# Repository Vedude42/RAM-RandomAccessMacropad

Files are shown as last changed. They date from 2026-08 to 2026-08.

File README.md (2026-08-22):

# RAM-RandomAccessMacropad
A macropad that is used for any random keyboard shortcuts and buttons that I dont have on my keyboard
MacroPad

# Schematics




# PCB





# Case







# FirmWare

right now, the firmware is just a numberpad, but when I assemble My macropad I'm going to set it to random miscellaneous shortcuts.

# Bom

You can find the Bom in the PCB Folder (Along with a zip file that you can import straight into jlcpcp for fabrication) with the footprints of the parts. keycaps are DSA 1us

- Seed XIAO RP2040 Microcontroller
- 16x Mechanical switches
- 1x 0.91 inch oled display
- 4 20mm m4 screws
- 16x dsa keycaps

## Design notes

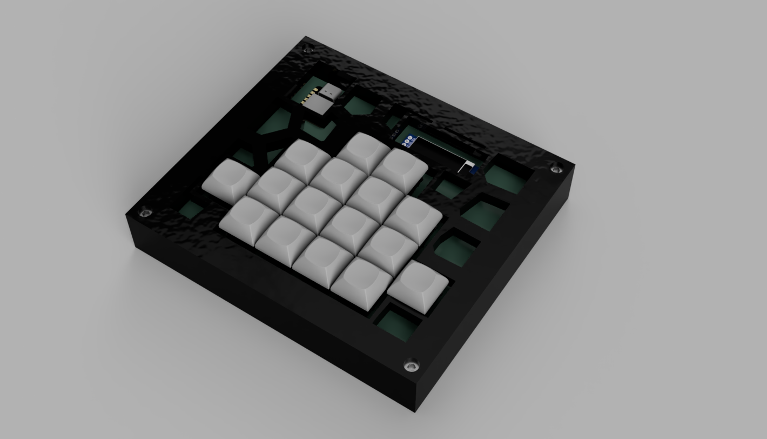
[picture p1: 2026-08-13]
MacroPad.png

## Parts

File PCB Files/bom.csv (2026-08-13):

Designator | Footprint | Quantity | Value | LCSC Part #
D1, D10, D11, D12, D13, D14, D15, D16, D2, D3, D4, D5, D6, D7, D8, D9 | D_DO-35_SOD27_P7.62mm_Horizontal | 16 | D
J1 | SSD1306-0.91-OLED-4pin-128x32 | 1 | Conn_01x04_Pin
SW1, SW10, SW11, SW12, SW13, SW14, SW15, SW16, SW2, SW3, SW4, SW5, SW6, SW7, SW8, SW9 | SW_Cherry_MX_1.00u_PCB | 16 | SW_Push_45deg
U1 | XIAO-Generic-Hybrid-14P-2.54-21X17.8MM | 1 | MOUDLE-SEEEDUINO-XIAO

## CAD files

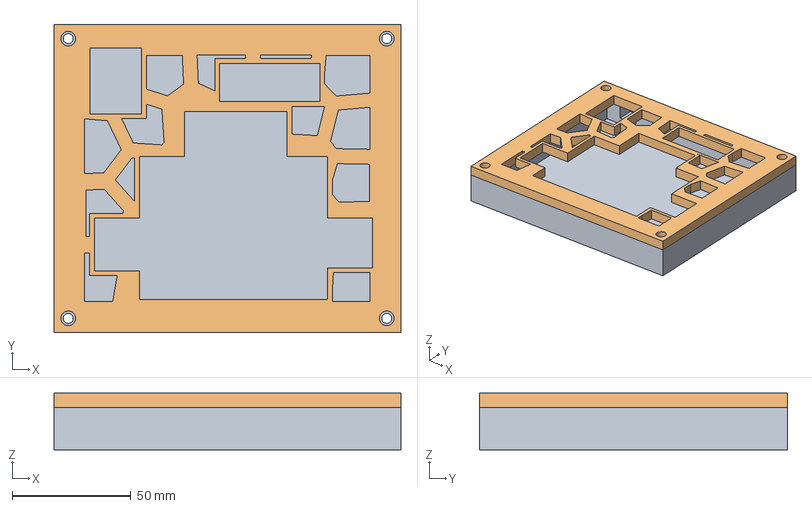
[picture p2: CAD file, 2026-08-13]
production/3D Elements/MacroPad.step
146.4 x 130.0 x 24.0 mm

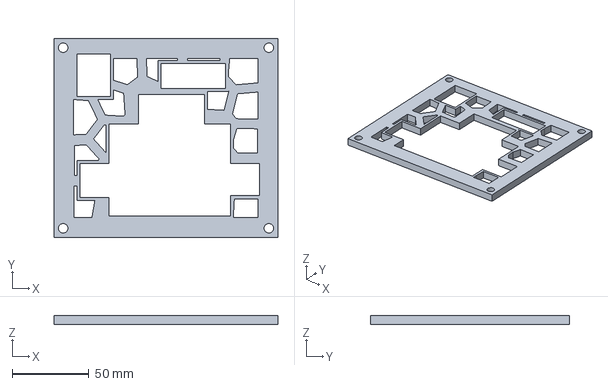
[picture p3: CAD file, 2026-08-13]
production/3D Elements/MacroPad Top Plate.step
146.4 x 130.0 x 6.00 mm

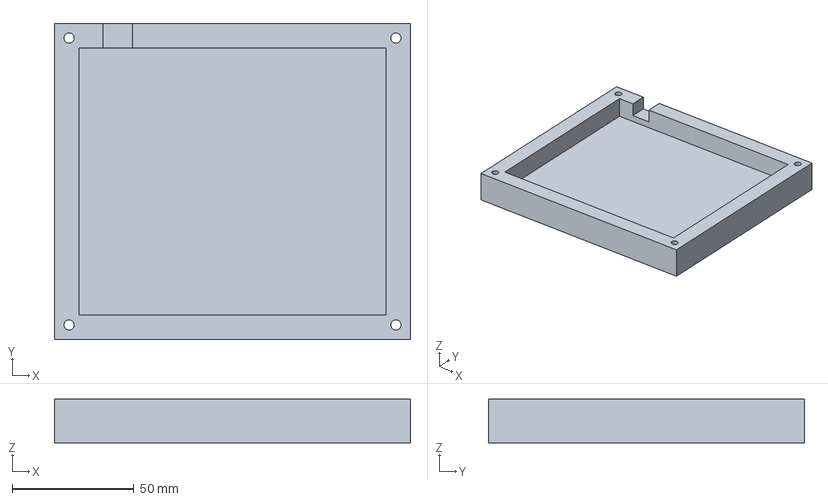
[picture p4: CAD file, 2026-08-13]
production/3D Elements/MacroPad Body.step
146.4 x 130.0 x 18.0 mm

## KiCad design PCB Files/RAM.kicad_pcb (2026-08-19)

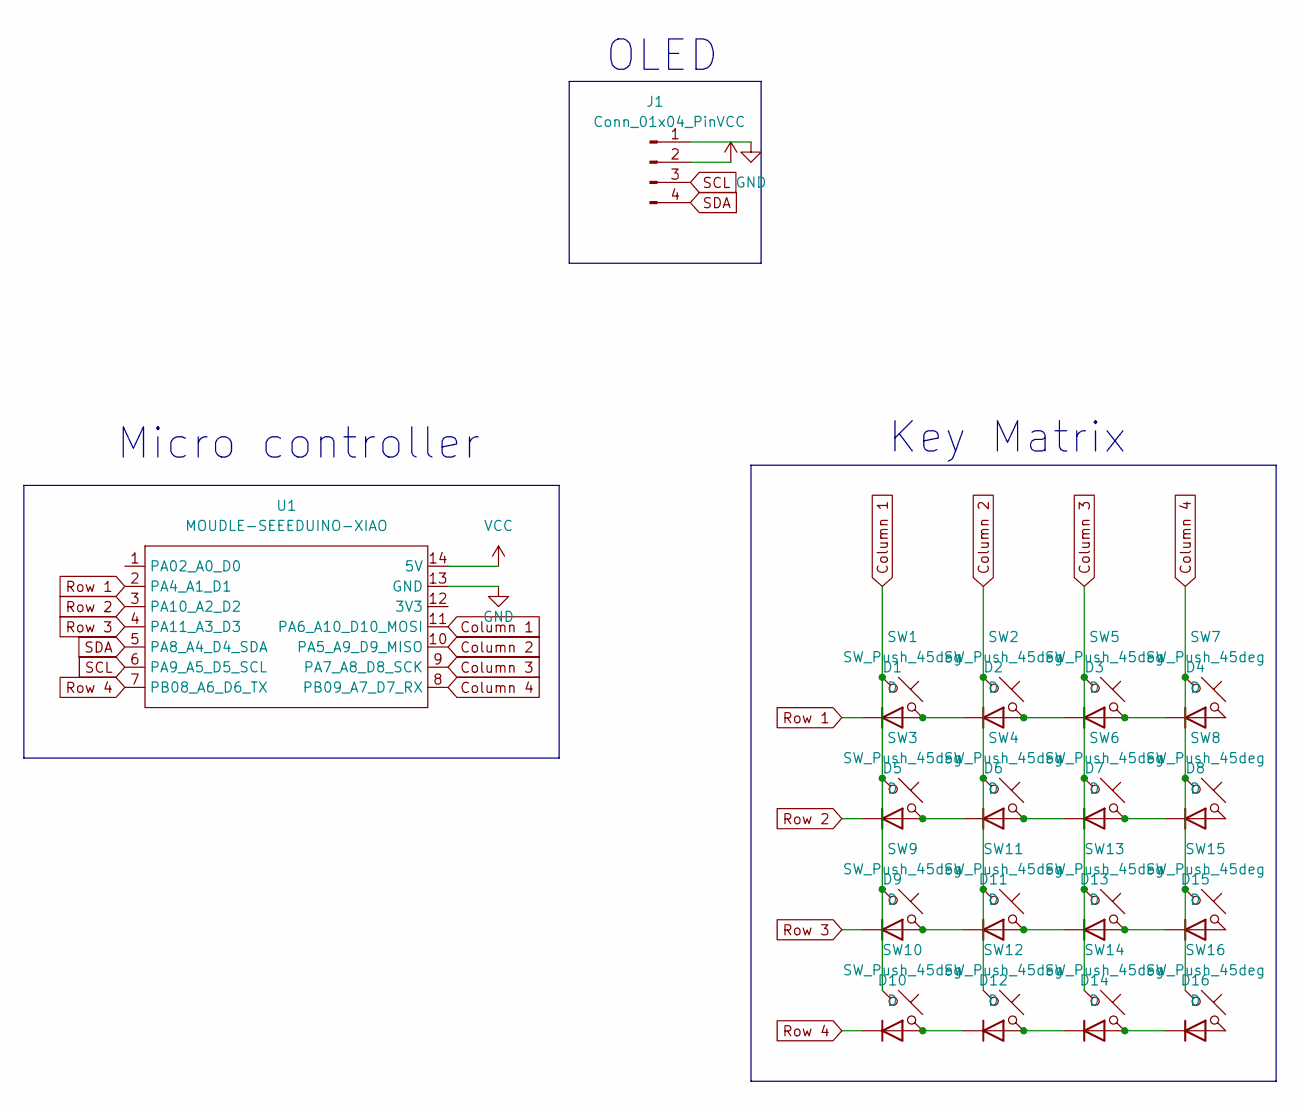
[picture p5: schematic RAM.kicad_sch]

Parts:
D1, D2, D3, D4, D5, D6, D7, D8, D9, D10, D11, D12, D13, D14, D15, D16: D; D_DO-35_SOD27_P7.62mm_Horizontal
J1: Conn_01x04_Pin; SSD1306-0.91-OLED-4pin-128x32
SW1, SW2, SW3, SW4, SW5, SW6, SW7, SW8, SW9, SW10, SW11, SW12, SW13, SW14, SW15, SW16: SW_Push_45deg; SW_Cherry_MX_1.00u_PCB
U1: MOUDLE-SEEEDUINO-XIAO; XIAO-Generic-Hybrid-14P-2.54-21X17.8MM

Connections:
Column 1: SW1.1, SW3.1, SW9.1, SW10.1, U1.11 (PA6_A10_D10_MOSI)
Column 2: SW2.1, SW4.1, SW11.1, SW12.1, U1.10 (PA5_A9_D9_MISO)
Column 3: SW5.1, SW6.1, SW13.1, SW14.1, U1.9 (PA7_A8_D8_SCK)
Column 4: SW7.1, SW8.1, SW15.1, SW16.1, U1.8 (PB09_A7_D7_RX)
GND: J1.1, U1.13 (GND)
unnamed: D1.2 (A), D2.1 (K), SW1.2
unnamed: D2.2 (A), D3.1 (K), SW2.2
unnamed: D3.2 (A), D4.1 (K), SW5.2
unnamed: D4.2 (A), SW7.2
unnamed: D5.2 (A), D6.1 (K), SW3.2
unnamed: D6.2 (A), D7.1 (K), SW4.2
unnamed: D7.2 (A), D8.1 (K), SW6.2
unnamed: D8.2 (A), SW8.2
unnamed: D10.2 (A), D12.1 (K), SW10.2
unnamed: D11.2 (A), D13.1 (K), SW11.2
unnamed: D9.2 (A), D11.1 (K), SW9.2
unnamed: D12.2 (A), D14.1 (K), SW12.2
unnamed: D13.2 (A), D15.1 (K), SW13.2
unnamed: D14.2 (A), D16.1 (K), SW14.2
unnamed: D15.2 (A), SW15.2
unnamed: D16.2 (A), SW16.2
Row 1: D1.1 (K), U1.2 (PA4_A1_D1)
Row 2: D5.1 (K), U1.3 (PA10_A2_D2)
Row 3: D9.1 (K), U1.4 (PA11_A3_D3)
Row 4: D10.1 (K), U1.7 (PB08_A6_D6_TX)
SCL: J1.3, U1.6 (PA9_A5_D5_SCL)
SDA: J1.4, U1.5 (PA8_A4_D4_SDA)
VCC: J1.2, U1.14 (5V)

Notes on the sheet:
OLED
Key Matrix
Micro controller

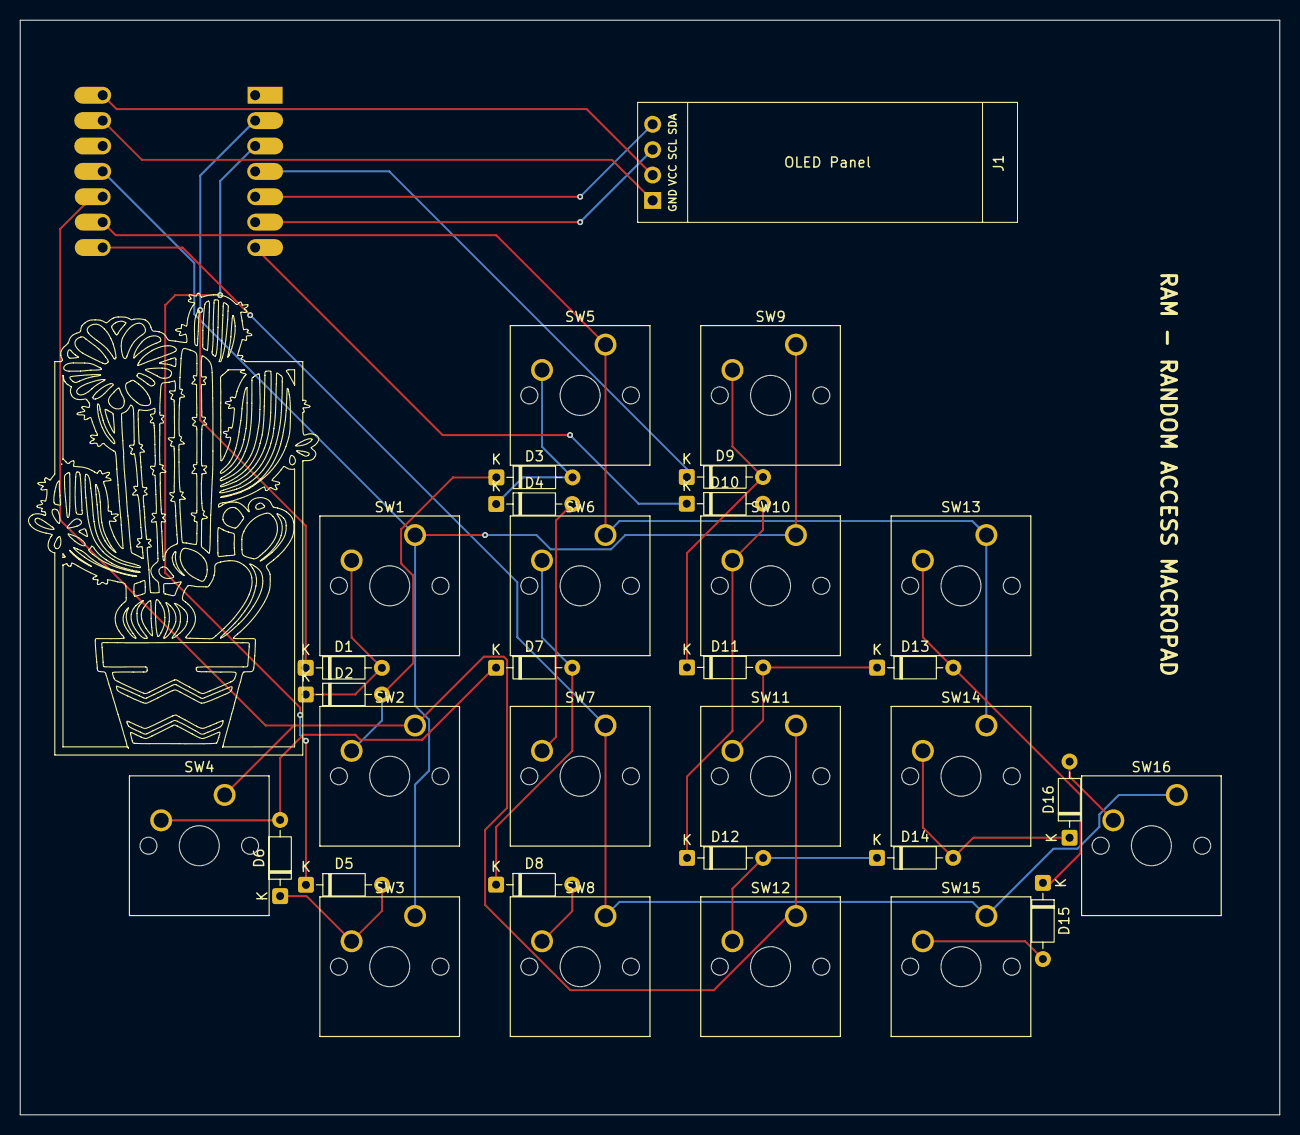
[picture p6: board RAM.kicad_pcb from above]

Board: 2 copper layers, 126.0 x 109.5 mm, 34 parts (1 on the bottom side), 28 nets.

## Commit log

2026-08-13 Rename Screenshot 2026-08-12 205504.png to PCB
2026-08-13 Rename Screenshot 2026-08-12 205533.png to PCB 3D Front
2026-08-13 Rename Screenshot 2026-08-12 205544.png to PCB 3D Back
2026-08-13 Rename Screenshot 2026-08-12 205605.png to Schematic
2026-08-13 Rename Screenshot 2026-08-12 205628.png to Oled Panel Schematic
2026-08-13 Rename Screenshot 2026-08-12 210923.png to Macropad Top Plate
2026-08-13 Rename MacroPad Body.step to 3D Elements/MacroPad Body.step
    [MacroPad Body.step]
2026-08-13 Rename MacroPad Top Plate.step to 3D Elements/MacroPad Top Plate.step
    [MacroPad Top Plate.step]
2026-08-13 Rename bom.csv to PCB Files/bom.csv
    [bom.csv]
2026-08-13 Rename Hackpad_tutorial.zip to PCB Files/RAM Fabrication.zip
2026-08-13 Update README with additional images and sections
    Added schematics, PCB, and case images to README.
2026-08-13 Fix typo in 'Schematics' section header
2026-08-13 Update README with additional sections
    Added PCB, Case, Firmware, and BOM sections to README.
2026-08-13 Rename Hackpad tutorial.zip to RAM PCBS.zip
2026-08-19 Rename Hackpad tutorial.kicad_pcb to RAMl.kicad_pcb
    [RAMl.kicad_pcb]
2026-08-19 Rename Hackpad tutorial.kicad_pro to RAM.kicad_pro
2026-08-19 Rename Hackpad tutorial.kicad_sch to RAM.kicad_sch
    [RAM.kicad_sch]
